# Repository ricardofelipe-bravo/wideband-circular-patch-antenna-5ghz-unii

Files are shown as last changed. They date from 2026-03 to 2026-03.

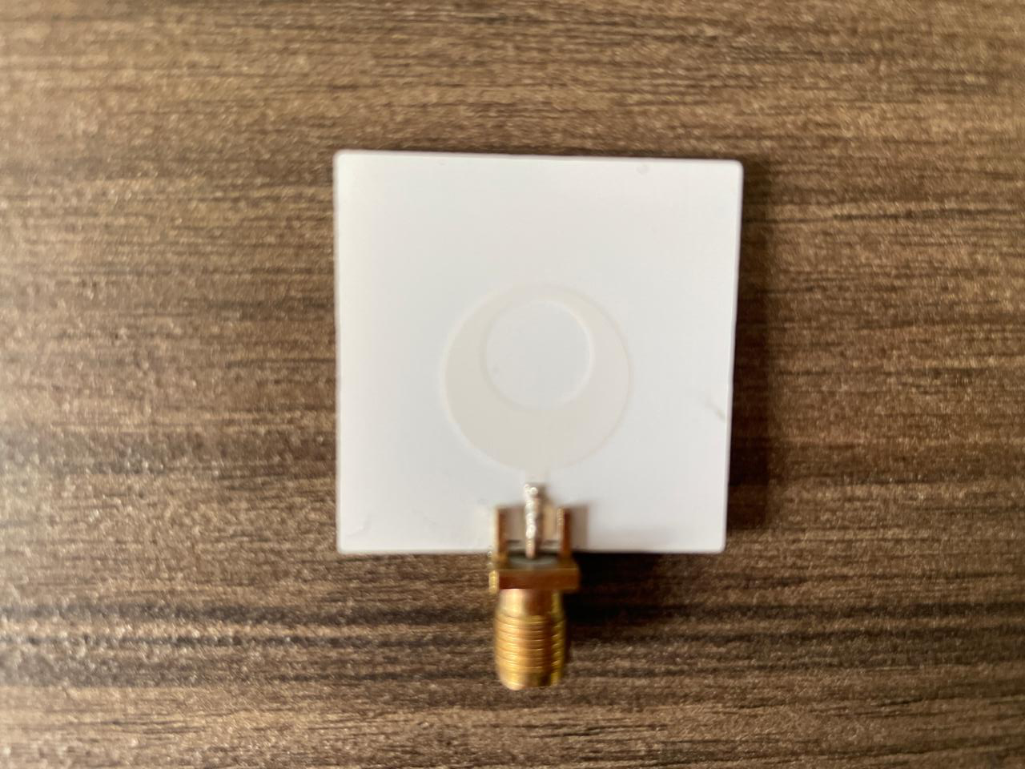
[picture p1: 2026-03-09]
Prototype/circular_patch_antenna_prototype_SMA.jpg

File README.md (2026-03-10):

# wideband-circular-patch-antenna-5ghz-unii

Design, simulation, fabrication, and experimental validation of a wideband circular microstrip patch antenna operating across the U-NII bands in the 5 GHz range.

The project covers the full development cycle: theoretical design based on the cavity model, electromagnetic simulation in FEKO, PCB layout in EasyEDA, physical fabrication via JLCPCB, and experimental S-parameter measurement using a vector network analyzer.

---

## Key Results

| Parameter | Simulated | Measured |
|---|---|---|
| Resonance frequency | 5.71 GHz | 5.485 GHz |
| Minimum S11 | −37.57 dB | −42.37 dB |
| Bandwidth (S11 < −10 dB) — full sweep | 1875 MHz (4.0–5.875 GHz) | 1770 MHz (4.03–5.80 GHz) |
| Bandwidth (S11 < −10 dB) — U-NII band only | 405 MHz (5.47–5.875 GHz) | 645 MHz (5.155–5.80 GHz) |
| Input impedance | 50 Ω | 50 Ω |

The ~225 MHz downward frequency shift between simulation and measurement is consistent with the typical permittivity variation of commercial FR4 and the slightly greater substrate thickness of the fabricated board (1.6 mm vs. 1.575 mm in simulation). Despite this shift, the fabricated prototype achieved stronger adaptation and a wider measured bandwidth than predicted, confirming the design operates across the target U-NII sub-bands.

### U-NII Band Coverage (S11 < −10 dB)

| Sub-band | Range | Simulated | Measured |
|---|---|---|---|
| U-NII-2C / U-NII-2e | 5.470–5.725 GHz | Almost complete | Full |
| U-NII-3 | 5.725–5.850 GHz | Full | Full |
| U-NII-4 / DSRC | 5.850–5.925 GHz | Partial | Full |

---

## Repository Structure

```
wideband-circular-patch-antenna-5ghz-unii/
│
├── simulation/      # FEKO simulation files (.fek, .feko, .out)
├── cad/             # STEP and FreeCAD geometry files
├── fabrication/     # DXF files, EasyEDA project and Gerbers
├── figures/         # Simulation plots, VNA data and comparison graphs
├── prototype/       # Photos of the fabricated prototype
└── README.md
```

---

## Design Overview

The antenna is a **circular patch** on FR4 substrate, fed by a microstrip line and coupled through a slot in the ground plane, designed for a 50 Ω input impedance. The design initially targeted 5.5 GHz using the cavity model. The resonance was then intentionally shifted to 5.72 GHz by adjusting the patch radius, slot dimensions, and feed line width — moving it toward the center of the U-NII band to maximize bandwidth coverage across U-NII-2C, U-NII-3, and U-NII-4.

### Design Parameters

| Parameter | Value |
|---|---|
| Substrate | FR4 (εr = 4.4, tan δ = 0.02) |
| Substrate thickness | 1.575 mm |
| Patch radius | 7.43 mm |
| Feed line width | 1.84 mm |
| Feed line length | 6.3 mm |
| Slot radius in patch | 4.31 mm |
| Slot width in ground plane | 19 mm |
| Substrate size | 30 × 30 mm |
| Design frequency | 5.5 GHz |
| Resonance frequency (simulated) | 5.72 GHz |

---

## Tools

| Tool | Purpose |
|---|---|
| FEKO (Altair) | Electromagnetic simulation |
| FreeCAD | CAD geometry adjustment and DXF export |
| EasyEDA | PCB layout and Gerber generation |
| JLCPCB | PCB fabrication |
| Vector Network Analyzer | Experimental S-parameter measurement |
| MATLAB | Data processing and simulation vs. measurement comparison |

---

## Authors

Ricardo Felipe Bravo Arevalo — `rifebrare@udenar.edu.co`
David Jesus Lara Revelo — `dxddavid17@udenar.edu.co`
Departamento de Ingeniería — Universidad de Nariño, Pasto, Colombia

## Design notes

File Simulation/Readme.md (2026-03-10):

# Simulation

This folder contains the FEKO electromagnetic simulation files for the individual circular patch antenna.

## Software

- **FEKO** (Altair) — Method of Moments (MoM) electromagnetic solver

## Contents

- **CadFEKO file** (`.fek`) — editable antenna model, open this to modify the geometry and re-run the simulation
- **PostFEKO file** (`.feko`) — results project file, open this to visualize S11, Smith chart, and radiation pattern without re-running
- **Solver output** (`.out`) — full solver log generated after running the simulation

## Simulation Configurations

Two frequency sweeps were used depending on the purpose:

| Configuration | Frequency Range | Points | Purpose |
|---|---|---|---|
| Individual antenna model | 3 – 7 GHz | 51 | Design and optimization of the patch element |
| Comparative analysis | 4 – 7 GHz | 101 | Overlay with VNA measurements (see `figures/`) |

## Key Simulation Parameters

| Parameter | Value |
|---|---|
| Substrate | FR4 (εr = 4.4, tan δ = 0.02, h = 1.575 mm) |
| Solver | Method of Moments (MoM) |
| Port impedance | 50 Ω |
| Resonance frequency | 5.72 GHz |
| Minimum S11 | −31.31 dB |
| Bandwidth (S11 < −10 dB) | 407 MHz (5.467 – 5.874 GHz) |

## Notes

The design initially targeted 5.5 GHz following the cavity model procedure. The resonance was intentionally shifted to 5.72 GHz by adjusting the patch radius, slot dimensions, and feed line width. This shift was deliberate — moving the resonance toward the center of the U-NII band increases the operational bandwidth and maximizes sub-band coverage.

The simulated bandwidth with S11 < −10 dB extends from **5.467 GHz to 5.874 GHz (407 MHz)**, covering virtually the entire upper U-NII spectrum:

| Sub-band | Range | Coverage |
|---|---|---|
| U-NII-2C / U-NII-2e | 5.470 – 5.725 GHz | Almost complete |
| U-NII-3 | 5.725 – 5.850 GHz | Full |
| U-NII-4 / DSRC | 5.850 – 5.925 GHz | Partial |

The final geometry was exported as a STEP file for fabrication (see `cad/`).

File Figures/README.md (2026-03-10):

# Figures

This folder contains simulation results, experimental measurements, and comparative visualizations for the circular patch antenna.

## Contents

| File | Description |
|---|---|
| `S11 Antena Individual simulacion.png` | S11 parameter from FEKO simulation — resonance at 5.72 GHz |
| `Antena Parche_s11_simulated_vs_measured.png` | S11 comparison generated in FEKO, overlaying simulation and VNA measurements. Shows resonance frequency, minimum S11, and bandwidth for both curves |
| `S11_simulation_vs_measured_matlab.png` | Same comparison regenerated in MATLAB from the raw data files |
| `Antena vista desde Feko.png` | 3D view of the antenna model as seen in FEKO |
| `CSV4.csv` | Raw S11 data measured with the Vector Network Analyzer (VNA) — imported into FEKO and MATLAB to generate the comparison plots |
| `antenadatos.s1p` | S11 simulation data exported from FEKO in Touchstone format — used as input for the MATLAB script |
| `Graficas_comparativa_antenas_simu_medicion.mlx` | MATLAB Live Script that loads `CSV4.csv` and `antenadatos.s1p` and generates the comparison plot |

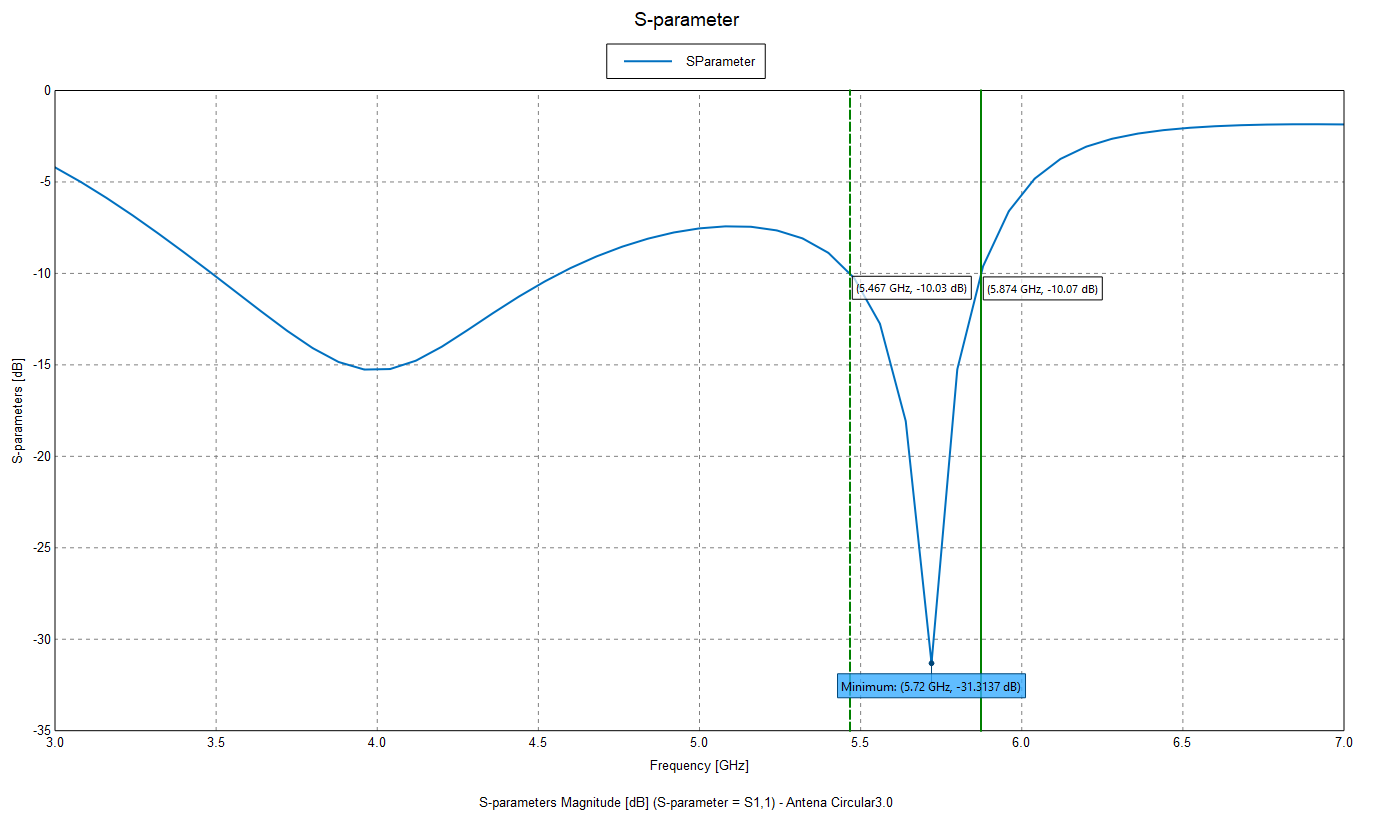
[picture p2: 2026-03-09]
Figures/s11 antena individual simulacion.png

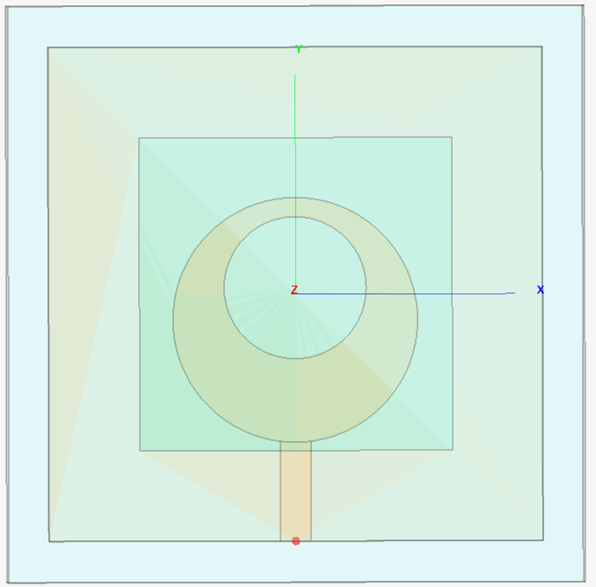
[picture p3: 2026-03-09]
Figures/Antena vista desde Feko.png

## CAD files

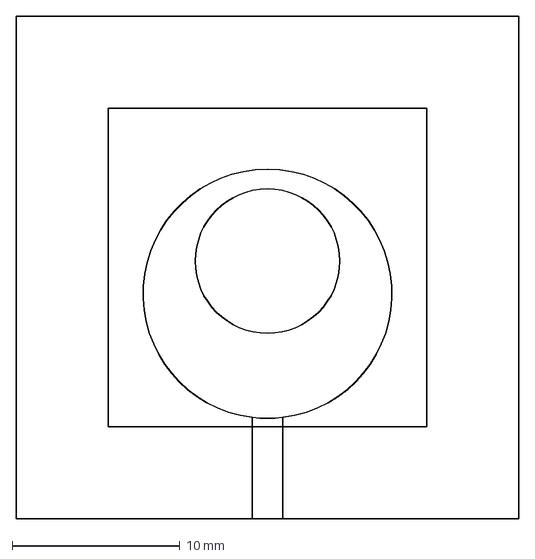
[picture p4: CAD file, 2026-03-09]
Fabrication/full model Antena Parche Circular.dxf
30.0 x 30.0 mm

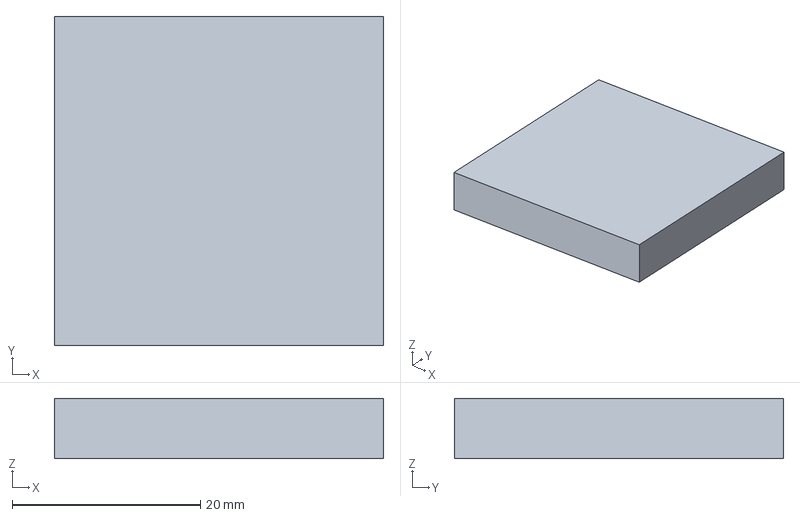
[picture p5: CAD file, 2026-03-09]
Cad/full model Antena Parche Circular.step
35.0 x 35.0 x 6.44 mm

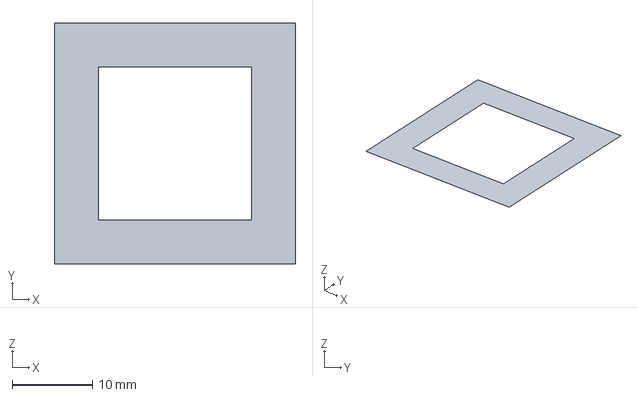
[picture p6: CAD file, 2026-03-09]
Cad/groundplane Parche Circular.step
30.0 x 30.0 x 0 mm

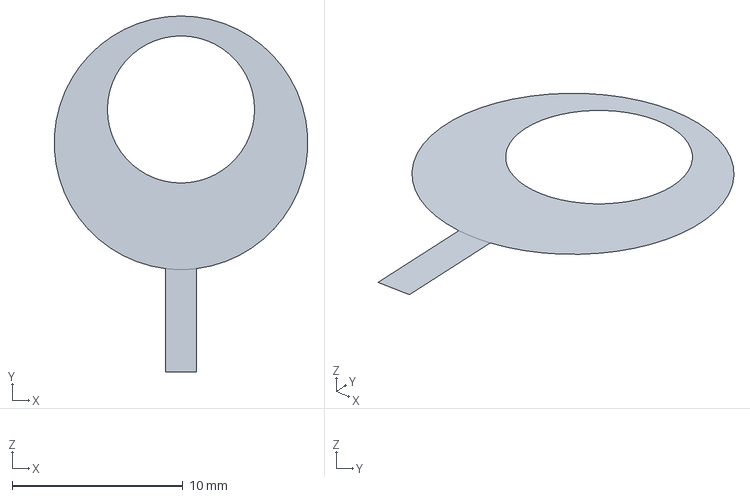
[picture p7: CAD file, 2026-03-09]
Cad/patch_feedline Antena .step
14.8 x 20.9 x 0 mm

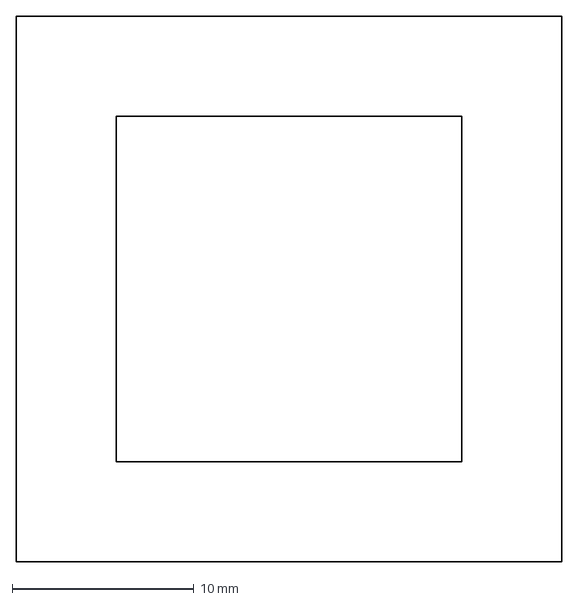
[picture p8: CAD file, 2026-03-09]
Fabrication/groundplane Parche Circular.dxf
30.0 x 30.0 mm

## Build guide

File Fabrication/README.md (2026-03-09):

# Fabrication

This folder contains the PCB layout and manufacturing files for the circular patch antenna prototype.

## Workflow

1. Final geometry exported from FEKO as **STEP files** (see `cad/` folder)
2. STEP files imported into **FreeCAD** for geometric adjustments
3. **DXF files** exported from FreeCAD and imported into **EasyEDA** to define the feed port, ground plane, and layer stack
4. **Gerber files** generated from EasyEDA and submitted to JLCPCB for fabrication
5. SMA edge connector soldered manually after receiving the board

## Contents

| File | Description |
|---|---|
| `Antena Parche Circular.dxf` | Patch and feed line exported from FreeCAD — ground plane slot not included, see separate file below |
| `groundplane Parche Circular.dxf` | Ground plane exported separately from FreeCAD to preserve the coupling slot geometry |
| `full model Antena Parche Circular.dxf` | Complete assembly exported from FreeCAD, used as visual reference |
| `Antena Parche Circular.epro` | EasyEDA project file — open this to edit the PCB layout and re-export Gerbers |
| `Gerber_Antena_Parche_Circular_PCB1_2026-03-09.zip` | Gerber files ready for PCB fabrication |

## Why Three DXF Files?

The ground plane contains a coupling slot that does not export correctly in the full model DXF. For this reason the geometry was split into separate files: one with the patch and feed line, and one with the ground plane including the slot. The third DXF is the full assembly exported from FreeCAD, useful as a visual reference.

To reproduce or modify the PCB layout, open `Antena Parche Circular.epro` directly in EasyEDA — all layers are already defined there and new Gerbers can be exported from it.

## PCB Specifications

| Parameter | Value |
|---|---|
| Substrate | FR4 |
| Substrate thickness | 1.6 mm |
| Board dimensions | 30 × 30 mm |
| Copper layers | 2 (patch + ground plane) |
| Fabrication service | JLCPCB (standard 2-layer) |
| Connector | SMA edge mount |

## Notes

The fabricated substrate thickness (1.6 mm) differs slightly from the simulation model (1.575 mm). Combined with the typical permittivity variation of commercial FR4, this accounts for the ~225 MHz downward frequency shift observed experimentally (resonance at 5.485 GHz vs. 5.71 GHz in simulation). Despite this shift, the prototype achieved a stronger adaptation (−42.4 dB) and a wider measured bandwidth than predicted.

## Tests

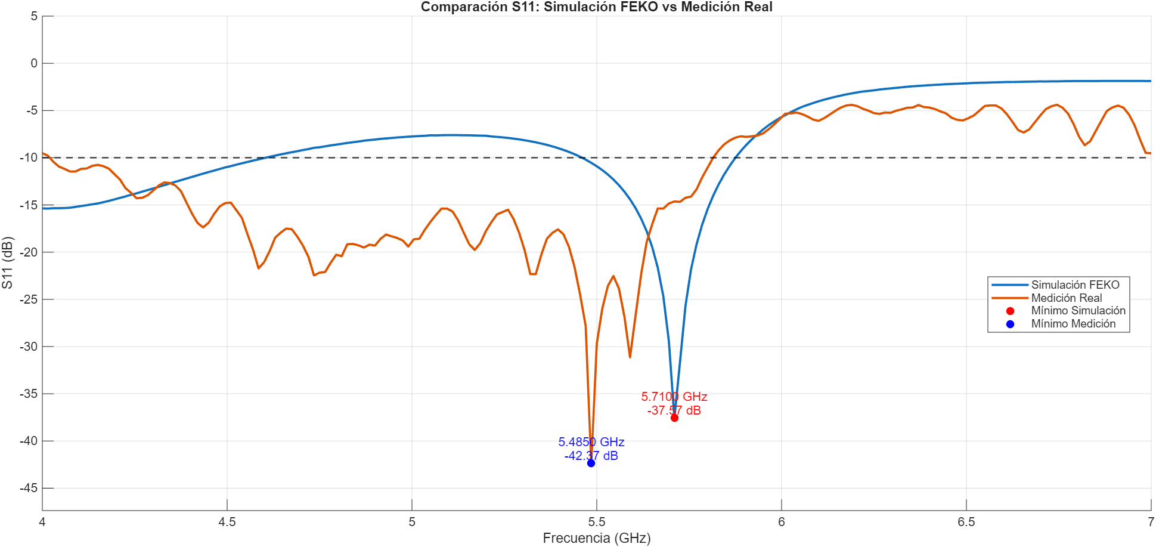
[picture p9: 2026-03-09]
Figures/S11_simulation_vs_measured_matlab.png
